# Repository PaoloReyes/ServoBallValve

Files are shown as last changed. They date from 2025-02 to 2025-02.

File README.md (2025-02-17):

# ServoBallValve

## Overview
This repository contains the code and design (PCB) for the Angled Controlled valve (ServoBallValve) module, which serves as an actuator for dispensing paint in the automatic paint machine. The ServoBallValve is responsible for controlling the flow of paint according to the desired angle.

## Features
- **Positional Control**: Uses a motor in a closed loop system to precisely control the angle of the valve.
- **Flow Regulation**: Regulates the paint flow rate based on the angle setpoint.
- **Sensor Integration**: Utilizes High resolution Potentiometer for position feedback and validation.

## Communication Protocol
The ServoBallValve module receives and sends commands via a predefined protocol:
- `50Hz Signal` - It is the wave carrier for the data.
- `MicroSeconds codification` - The data is codified in the pulse width of the signal by sending a high pulse in the range of 1000 to 2000 microseconds.

## Troubleshooting
| Issue | Possible Cause | Solution |
|---|---|---|
| Incorrect positioning| Calibration error | Re-run calibration sequence |
| No response | Communication failure | Verify communication wiring and settings |
| Erratic flow | Sensor malfunction or misalignment| Check sensor connections and alignment |

## Contributors
- **Paolo Reyes** - Lead Developer

## License
This project is licensed under the MIT License - see the LICENSE file for details.

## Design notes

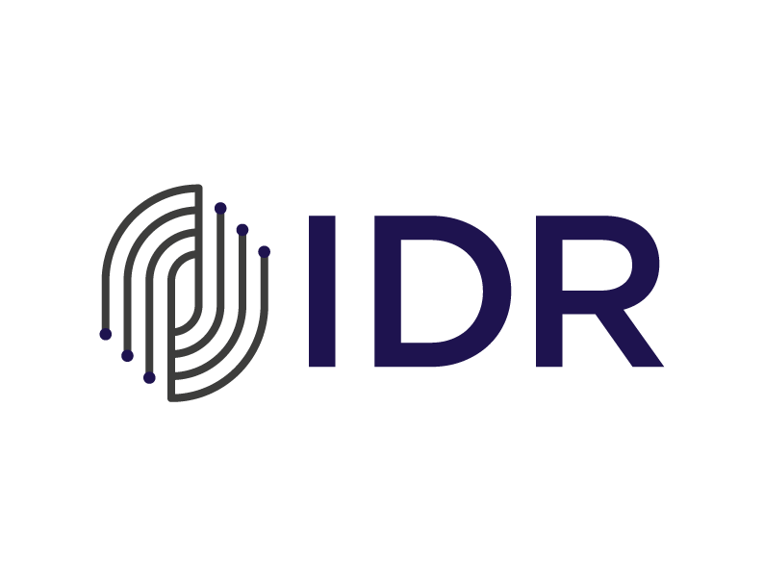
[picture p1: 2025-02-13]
Hardware/Assets/idr.png

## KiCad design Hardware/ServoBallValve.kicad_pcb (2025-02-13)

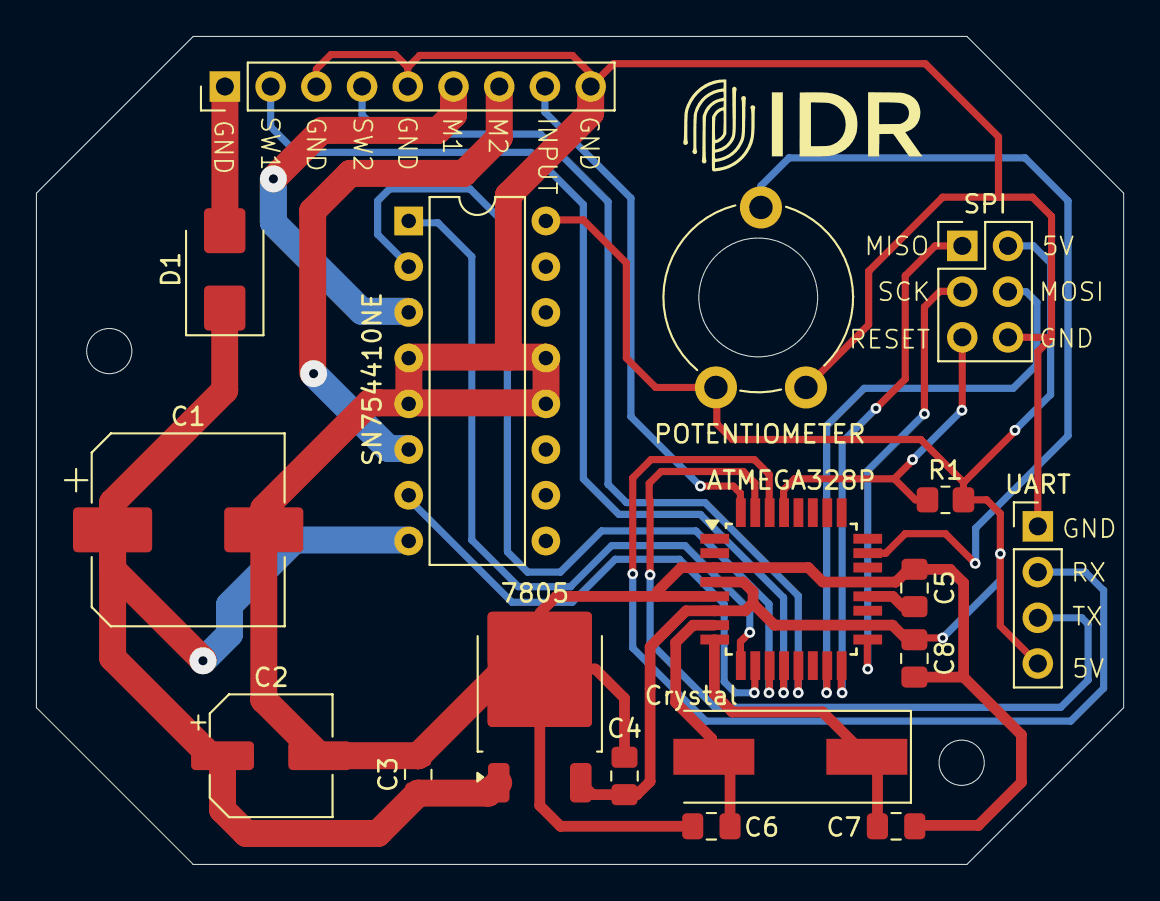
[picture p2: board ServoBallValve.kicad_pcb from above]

Board: 2 copper layers, 60.4 x 46.0 mm, 18 parts (0 on the bottom side), 22 nets.

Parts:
7805: L7805; TO-252-2
ATMEGA328P: ATmega328P-A; TQFP-32_7x7mm_P0.8mm
C1: Capacitor 220uf; CP_Elec_10x10.5
C2: Capacitor 100uf; CP_Elec_6.3x7.7
C3: Capacitor 4.7uf; C_0805_2012Metric_Pad1.18x1.45mm_HandSolder
C4: Capacitor 2.2uf; C_0805_2012Metric_Pad1.18x1.45mm_HandSolder
C5, C8: Capacitor 100nf; C_0805_2012Metric_Pad1.18x1.45mm_HandSolder
C6, C7: Capacitor 22pf; C_0805_2012Metric_Pad1.18x1.45mm_HandSolder
Crystal: 16MHzCrystal; Crystal_SMD_HC49-SD
D1: US2AA; D_SMB
J3: Conn_01x09_Socket; PinHeader_1x09_P2.54mm_Vertical
POTENTIOMETER: R_Potentiometer; Potentiometer_Piher_PT-10-V10_Vertical_Hole
R1: Resistor 1K; R_0805_2012Metric_Pad1.20x1.40mm_HandSolder
SN754410NE: L293D; DIP-16_W7.62mm
SPI: Conn_02x03_Counter_Clockwise; PinHeader_2x03_P2.54mm_Vertical
UART: Conn_01x04_Socket; PinHeader_1x04_P2.54mm_Vertical

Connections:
5V: 7805.3 (OUT), ATMEGA328P.4 (VCC), ATMEGA328P.6 (VCC), ATMEGA328P.18 (AVCC), C4.1, C8.1, POTENTIOMETER.3, R1.2, SN754410NE.16 (VCC1), SPI.2, UART.4
24V: 7805.1 (IN), C1.1, C2.1, C3.1, D1.1 (K), SN754410NE.8 (VCC2)
24VINPUT: D1.2 (A), J3.1
ENA: ATMEGA328P.9 (PD5), SN754410NE.1 (EN1,2)
GND: 7805.2 (GND), ATMEGA328P.3 (GND), ATMEGA328P.5 (GND), ATMEGA328P.21 (GND), C1.2, C2.2, C3.2, C4.2, C5.1, C6.2, C7.2, C8.2, J3.3, J3.5, J3.9, POTENTIOMETER.1, SN754410NE.4 (GND), SN754410NE.5 (GND), SN754410NE.12 (GND), SN754410NE.13 (GND), SPI.6, UART.1
IN1: ATMEGA328P.11 (PD7), SN754410NE.2 (1A)
IN2: ATMEGA328P.10 (PD6), SN754410NE.7 (2A)
M1: J3.6, SN754410NE.3 (1Y)
M2: J3.7, SN754410NE.6 (2Y)
MISO: ATMEGA328P.16 (PB4), SPI.1
MOSI: ATMEGA328P.15 (PB3), SPI.4
unnamed: ATMEGA328P.20 (AREF), C5.2
unnamed: ATMEGA328P.23 (PC0), POTENTIOMETER.2
unnamed: ATMEGA328P.7 (XTAL1/PB6), C6.1, Crystal.2
unnamed: ATMEGA328P.8 (XTAL2/PB7), C7.1, Crystal.1
RESET: ATMEGA328P.29 (~RESET/PC6), R1.1, SPI.5
RX: ATMEGA328P.30 (PD0), UART.2
S1.1: ATMEGA328P.12 (PB0), J3.2
S2.1: ATMEGA328P.13 (PB1), J3.4
SCK: ATMEGA328P.17 (PB5), SPI.3
Signal: ATMEGA328P.32 (PD2), J3.8
TX: ATMEGA328P.31 (PD1), UART.3

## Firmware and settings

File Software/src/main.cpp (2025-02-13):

#include <constants.h>

#ifdef MAIN_CPP
  #include <valve.h>
  #include <utils.h>

  Valve valve(IN_1, IN_2, EN_A, POT_PIN, OPEN_LIMIT, CLOSE_LIMIT, INTERRUPT_PIN, KP, KI, KD);
  uint16_t opening_limit, closing_limit;

  void setup() {
    Serial.begin(115200);
    opening_limit = read_16_bit_value_from_eeprom(0);
    closing_limit = read_16_bit_value_from_eeprom(2);
    valve.init(opening_limit, closing_limit);
  }

  void loop() {
    valve.follow_setpoint();
  }

  ISR(TIMER1_OVF_vect) {
    TCNT1 = ValveNS::TIMER_VALVE_PRELOAD;
    valve.update(&valve);
  }
#endif

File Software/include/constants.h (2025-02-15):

#define POT_PIN A0
#define EN_A 5
#define IN_1 6
#define IN_2 7
#define OPEN_LIMIT 9
#define CLOSE_LIMIT 8
#define INTERRUPT_PIN 2
#define KP 16.5
#define KI 12.5
#define KD 1.9

#define MAIN_CPP

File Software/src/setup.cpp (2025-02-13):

#include <constants.h>

#ifdef SETUP_CPP
  #include <valve.h>
  #include <utils.h>

  Valve valve(IN_1, IN_2, EN_A, POT_PIN, OPEN_LIMIT, CLOSE_LIMIT, INTERRUPT_PIN);

  void setup() {
    Serial.begin(115200);
    valve.open_until_hit();
    delay(3000);
    save_16_bit_value_to_eeprom(valve.get_position(), 0);
    valve.close_until_hit();
    delay(3000);
    save_16_bit_value_to_eeprom(valve.get_position(), 2);
  }

  void loop() {
    Serial.print(read_16_bit_value_from_eeprom(0));
    Serial.print(" ");
    Serial.println(read_16_bit_value_from_eeprom(2));
  }
#endif

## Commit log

2025-02-13 feat(ServoBallValve): Hardware and Software Release
    [ServoBallValve.kicad_pcb, ServoBallValve.kicad_sch]
2025-02-17 feat(ServoBallValve): Hardware and Software Release for 3/4 valve with first software corrected for mechanical issues
